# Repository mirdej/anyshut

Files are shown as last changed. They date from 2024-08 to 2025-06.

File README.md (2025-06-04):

# THE   [ a n y m a ]   SHUTTER

Versatile, modular ,3D-printed, remote controlled shutter for video beamers and other light sources.
 
- Can be mounted to the projector in various ways
- Opens to the front or to the side
- Test button on the device
- Wireless remote control through ESP-Now over ~25m
- DMX input to the remote, no need to install cables

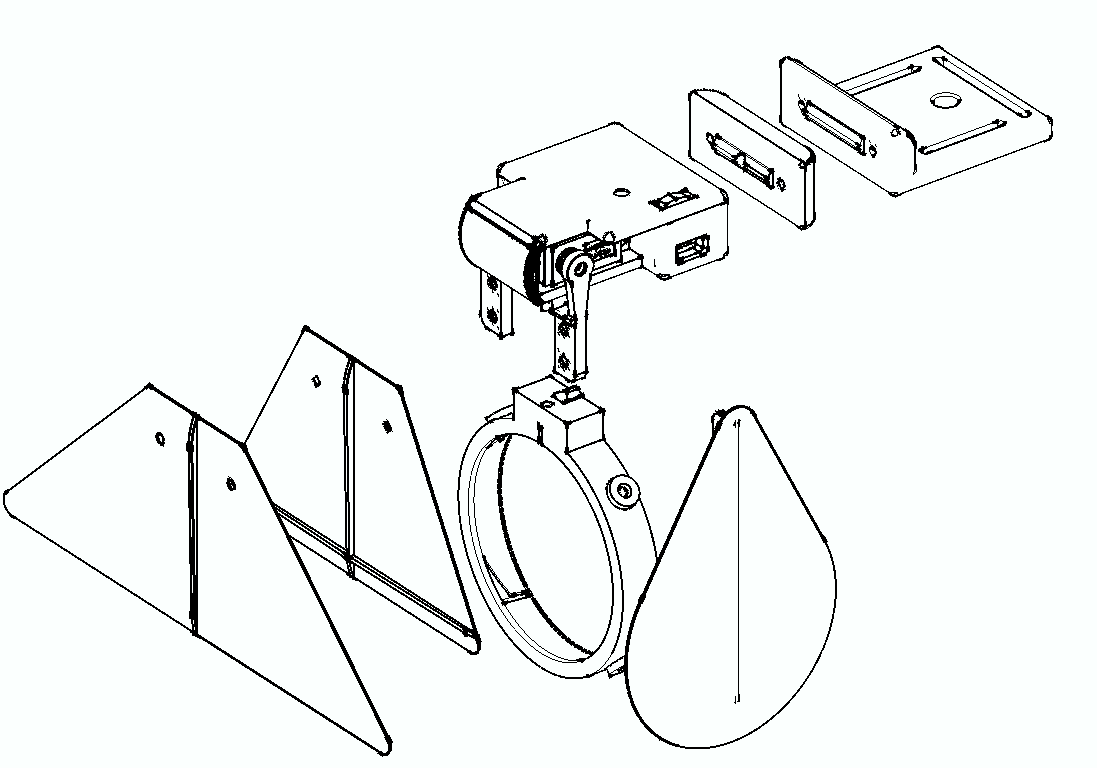
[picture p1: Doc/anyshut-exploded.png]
exploded view


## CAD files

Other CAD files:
Hardware/3D/AnyShut.skp
Hardware/3D/AnyShut~.skp

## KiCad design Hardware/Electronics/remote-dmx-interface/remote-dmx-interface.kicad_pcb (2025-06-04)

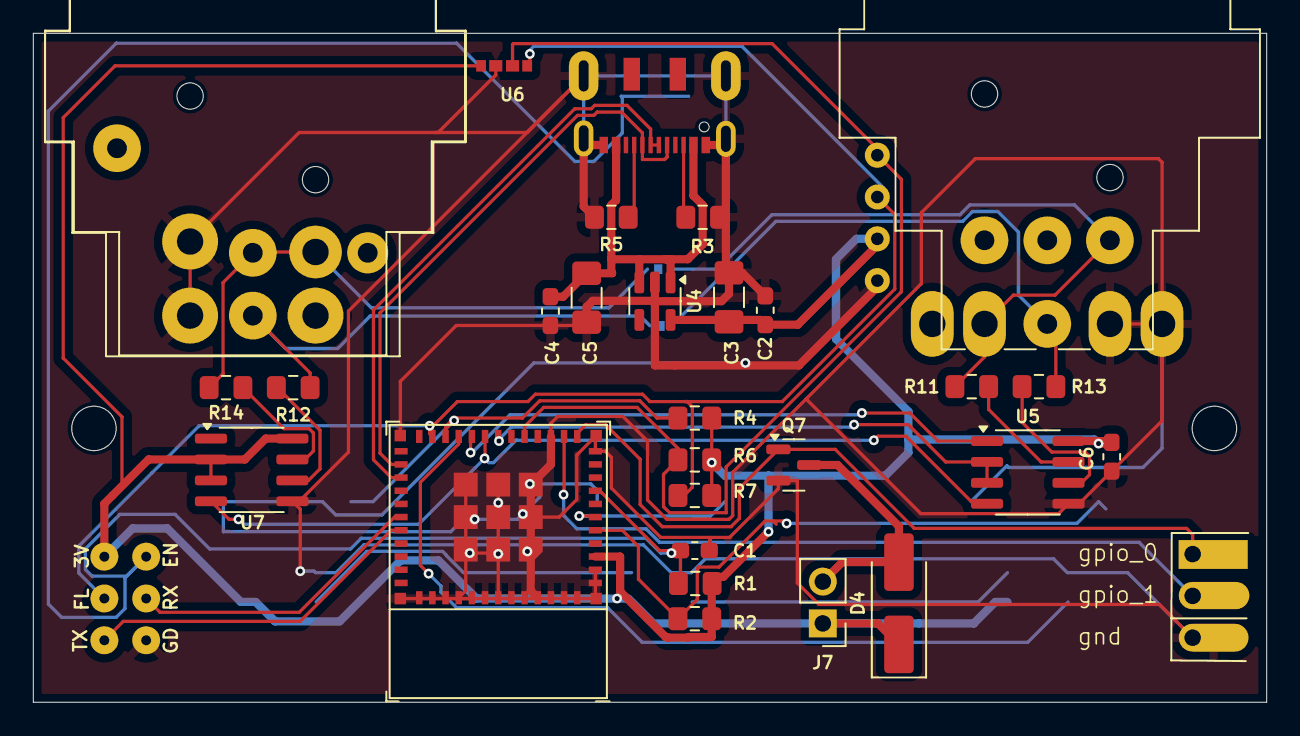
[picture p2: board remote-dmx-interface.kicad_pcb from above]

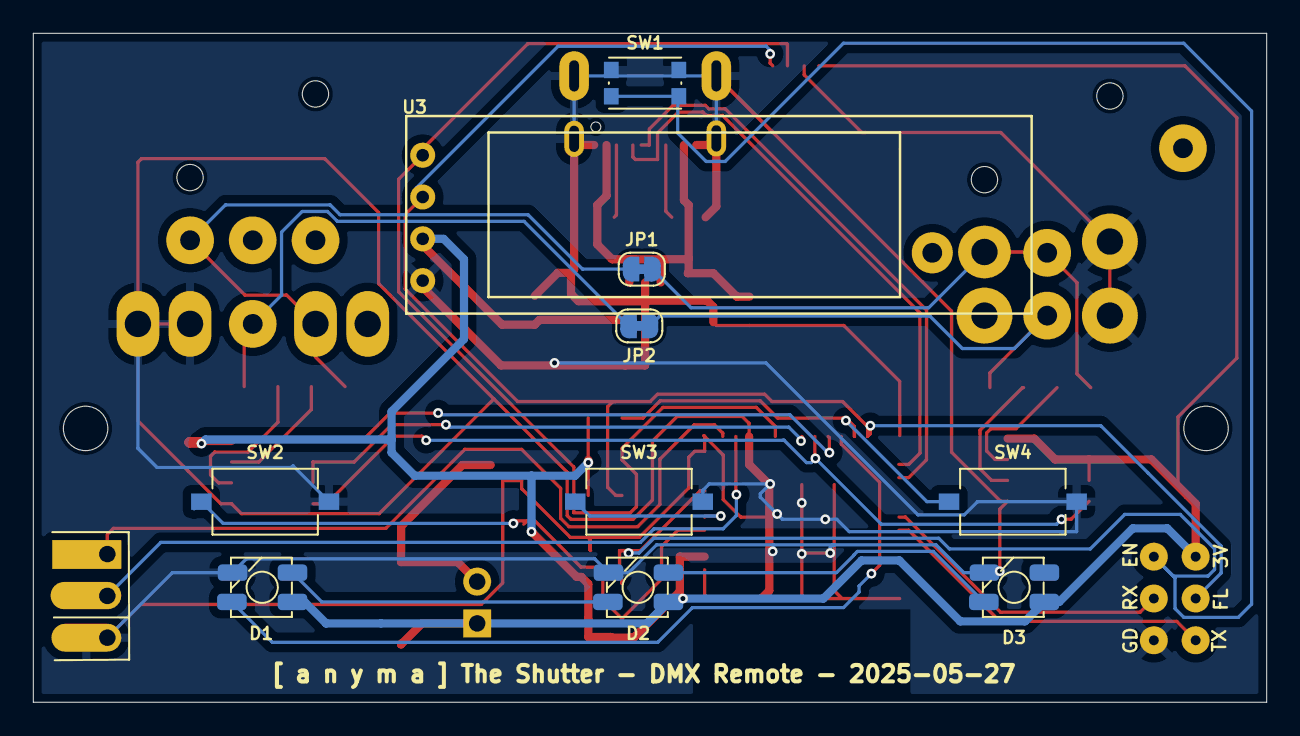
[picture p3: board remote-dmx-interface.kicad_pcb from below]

Board: 2 copper layers, 74.9 x 40.6 mm, 42 parts (11 on the bottom side), 32 nets.

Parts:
C1: 1u; C_0603_1608Metric_Pad1.05x0.95mm_HandSolder
C2, C4, C6: 100n; C_0603_1608Metric_Pad1.05x0.95mm_HandSolder
C3, C5: 10u; C_1206_3216Metric_Pad1.42x1.75mm_HandSolder
D1, D2, D3: SK6812MINI; SK6812-MINI-HS
D4: 1N4148WT; D_SMA_Handsoldering
H2, H5: MountingHole; MountingHole_2.7mm_M2.5_DIN965
J2: Prog; ESP-POGO-PROG-THT
J3: USB_C_Receptacle_USB2.0; JAE_USB-C_SJ122205
J4: DMX-OUT; Jack_XLR_Neutrik_3+5Pin_Female
J5: spare; ComboPinhead_03
J6: DMX-IN; Jack_XLR_Neutrix__3+5Pin_Male
J7: Vibro; PinHeader_1x02_P2.54mm_Vertical
JP1: Cut for MERGER Mode; SolderJumper-2_P1.3mm_Bridged_RoundedPad1.0x1.5mm
JP2: Cut for MERGER mode; SolderJumper-2_P1.3mm_Bridged_RoundedPad1.0x1.5mm
Q7: IRLML0030TRPBF; SOT-23
R1, R2, R3, R4, R5, R6, R7: 5k1; R_0805_2012Metric_Pad1.15x1.40mm_HandSolder
R11, R13: 22; R_0805_2012Metric_Pad1.15x1.40mm_HandSolder
R12, R14: (22); R_0805_2012Metric_Pad1.15x1.40mm_HandSolder
SW1: Reset; SW_Push_1P1T_NO_CK_KMR2
SW2: Btn-1; SW_Tactile_SPST_NO_Straight_CK_PTS636Sx25SMTRLFS
SW3: Btn-2; SW_Tactile_SPST_NO_Straight_CK_PTS636Sx25SMTRLFS
SW4: Btn-3; SW_Tactile_SPST_NO_Straight_CK_PTS636Sx25SMTRLFS
U1: ESP32-C3-MINI-1
U3: i2c-display128x32; Bangood-OLED-128x32
U4: XC6220B331MR; SOT-23-5
U5: SP3485EN; SOIC-8_3.9x4.9mm_P1.27mm
U6: VEML3328; VEML3328SL
U7: (SP3485EN) for MERGER Mode; SOIC-8_3.9x4.9mm_P1.27mm

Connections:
+3V3: C2.1, C3.1, C6.1, D1.4 (VDD), D2.4 (VDD), D3.4 (VDD), D4.1 (K), J2.1, J7.1, R1.1, R2.1, R4.1, R6.1, R7.1, U1.3 (3V3), U3.2 (VCC), U4.5 (VOUT), U5.8 (VCC), U6.1 (VCC), U7.2 (~RE), U7.3 (DE), U7.8 (VCC)
+5V: C4.1, C5.1, J3.A4 (VBUS), J3.A9 (VBUS), U4.1 (VIN), U4.3 (CE)
/DMX_DIR: U1.18 (GPIO4/ADC1_CH4), U5.2 (~RE), U5.3 (DE)
/DMX_RX: U1.20 (GPIO6), U5.1 (RO)
/DMX_TX: U1.19 (GPIO5/ADC2_CH0), U5.4 (DI), U7.4 (DI)
/en: C1.1, J2.2, R1.2, SW1.2, U1.8 (EN/CHIP_PU)
/flash: J2.3, R7.2, U1.23 (GPIO9), U3.3 (SCL), U6.4 (SCL)
/gpio_0: J5.1, Q7.1 (G), U1.12 (GPIO0/ADC1_CH0/XTAL_32K_P)
/gpio_1: J5.2, U1.13 (GPIO1/ADC1_CH1/XTAL_32K_N)
/pix: D1.3 (DIN), U1.21 (GPIO7)
/rx: J2.4, U1.30 (GPIO20/U0RXD)
/sda: R6.2, U1.16 (GPIO10), U3.4 (SDA), U6.3 (SDA)
/strap1: R4.2, SW4.1, U1.22 (GPIO8)
/strap2: R2.2, SW2.1, U1.5 (GPIO2/ADC1_CH2)
/tx: J2.5, U1.31 (GPIO21/U0TXD)
/usb+: J3.A6 (D+), J3.B6 (D+), U1.27 (GPIO19/USB_D+)
/usb-: J3.A7 (D-), J3.B7 (D-), U1.26 (GPIO18/USB_D-)
GND: C1.2, C2.2, C3.2, C4.2, C5.2, C6.2, D1.2 (VSS), D2.2 (VSS), D3.2 (VSS), J2.6, J3.A1 (GND), J3.A12 (GND), J3.S1 (SHIELD), J4.1, J5.3, J6.1, Q7.2 (S), R3.2, R5.2, SW1.1, SW2.2, SW3.2, SW4.2, U1.1 (GND), U1.2 (GND), U1.11 (GND), U1.14 (GND), U1.36 (GND), U1.37 (GND), U1.38 (GND), U1.39 (GND), U1.40 (GND), U1.41 (GND), U1.42 (GND), U1.43 (GND), U1.44 (GND), U1.45 (GND), U1.46 (GND), U1.47 (GND), U1.48 (GND), U1.49 (GND), U1.50 (GND), U1.51 (GND), U1.52 (GND), U1.53 (GND), U3.1 (GND), U4.2 (GND), U5.5 (GND), U6.2 (GND), U7.5 (GND)
unnamed: D1.1 (DOUT), D2.3 (DIN)
unnamed: D2.1 (DOUT), D3.3 (DIN)
unnamed: D4.2 (A), J7.2, Q7.3 (D)
unnamed: J3.A5 (CC1), R3.1
unnamed: J3.B5 (CC2), R5.1
unnamed: J6.2, JP1.1 (A), R11.1
unnamed: J4.2, JP1.2 (B), R14.1
unnamed: J6.3, JP2.1 (A), R13.1
unnamed: J4.3, JP2.2 (B), R12.1
unnamed: SW3.1, U1.6 (GPIO3/ADC1_CH3)
unnamed: R13.2, U5.6 (A)
unnamed: R11.2, U5.7 (B)
unnamed: R12.2, U7.6 (A)
unnamed: R14.2, U7.7 (B)

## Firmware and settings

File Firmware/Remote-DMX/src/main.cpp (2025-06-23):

#include <Arduino.h>
#include <FastLED.h>
#include "Display.h"
#include <Agora.h>
#include <esp_dmx.h>

#define PING_INTERVAL 1000

dmx_port_t dmxPort = 1;
#define RX_SIZE 512
byte data[RX_SIZE];

bool dmxIsConnected = false;

unsigned long lastInteraction = 0;
unsigned long lastUpdate = millis();

const int NUM_BTNS = 3;
const int PIN_BTN[NUM_BTNS] = {2, 3, 8};

const int NUM_PIXELS = 3;
CRGB pixel[NUM_PIXELS];
CRGB pixel_buf[NUM_PIXELS];
Preferences preferences;

#define PIN_DMX_RX 6
#define PIN_PIX 7

#define MESS_GET_SHUTTER 1
#define MESS_SET_SHUTTER 2

typedef struct esp_now_message
{
  //  uint8_t mac[6];
  uint8_t message;
  uint8_t param;
} esp_now_message;

int last_btn[NUM_BTNS];
int dmx_address = 1; // DMX address starts at 1
int shutter_closed = 1;

//--------------------------------------------------------------------------------

void updateDisplay()
{
  char buf[8];
  sprintf(buf, "%03d", dmx_address);
  if (dmxIsConnected)
  {
    display("    DMX OK    ", buf);
  }
  else
  {

    display("---No DMX---", buf);
  }
}

//--------------------------------------------------------------------------------
// Callback when data is received
void OnDataRecv(const uint8_t *mac, const uint8_t *incomingData, int len)
{
  Serial.printf("Message from Controller: %s\n", incomingData);
  if (!strcmp((const char *)incomingData, "OPEN"))
  {
    shutter_closed = 0;
  }
  else if (!strcmp((const char *)incomingData, "CLOSED"))
  {
    shutter_closed = 1;
  }
}

//----------------------------------------------------------------------------------------
//																				                                        LED Task

void led_task(void *)
{

  FastLED.addLeds<SK6812, PIN_PIX, GRB>(pixel, NUM_PIXELS);
  FastLED.setBrightness(250);
  for (int hue = 0; hue < 360; hue++)
  {
    fill_rainbow(pixel, NUM_PIXELS, hue, 7);
    delay(5);
    FastLED.show();
  }

  log_v("Running Led task");

  while (1)
  {
    fill_solid(pixel, NUM_PIXELS, Agora.connected() ? CRGB(6, 6, 6) : CRGB::DarkBlue);
    pixel[1] = shutter_closed ? CRGB::Red : CRGB::Green; // Button 2 shows shutter status
    for (int i = 0; i < NUM_BTNS; i++)
    {
      if (!digitalRead(PIN_BTN[i]))
      {
        pixel[i] = CRGB::LightCyan;
      }
    }
    FastLED.show();
    vTaskDelay(pdMS_TO_TICKS(40)); // ~25 fps display
  }

  vTaskDelete(NULL); // we never get here
}

//----------------------------------------------------------------------------------------
void toggleShutter()
{
  char buf[20];
  memset(buf, 0, sizeof(buf));
  sprintf(buf, "%s", shutter_closed ? "OPEN" : "CLOSE");
  Agora.tell(buf, sizeof(buf));
}
//----------------------------------------------------------------------------------------
//																				                                      Button Task

void button_task(void *)
{
  int last_button_state[NUM_BTNS];
  unsigned long lastButtonPress[NUM_BTNS] = {0, 0, 0};
  int button_state;
  int step = 1;

  for (int i = 0; i < NUM_BTNS; i++)
  {
    pinMode(PIN_BTN[i], INPUT_PULLUP);
    last_button_state[i] = digitalRead(PIN_BTN[i]);
  }

  Serial.printf("Running Button task");
  while (1)
  {
    int lastDmxAddress = dmx_address;
    for (int i = 0; i < NUM_BTNS; i++)
    {
      button_state = digitalRead(PIN_BTN[i]);
      if (i == 1)
      {
        step = button_state ? 1 : 10; // Button 2 changes step size
      }

      if (button_state != last_button_state[i])
      {
        last_button_state[i] = button_state;
        if (!button_state)
        {
          Serial.printf("Button %d pressed\n", i);
          lastButtonPress[i] = millis();
          if (i == 0)
          {
            dmx_address -= step;
          }
          else if (i == 1) // Button 2
          {
            toggleShutter();
          }
          else if (i == 2)
          {
            dmx_address += step;
          }
          else
          {
            lastButtonPress[i] = 0;
          }
        }
        else
        {
          lastButtonPress[i] = 0;
        }
      }

      if (lastButtonPress[i] > 0 && (millis() - lastButtonPress[i]) > 126)
      {
        lastButtonPress[i] = millis(); // reset button press
        if (i == 0)                    // Button 1
        {
          dmx_address -= step;
        }
        else if (i == 2) // Button 3
        {
          dmx_address += step;
        }
      }
    }
    if (dmx_address < 1)
    {
      dmx_address += 512; // wrap around to 512
    }
    if (dmx_address > 512)
    {
      dmx_address -= 512; // wrap around to 1
    }
    if (dmx_address != lastDmxAddress)
    {
      lastInteraction = millis();
      updateDisplay();
    }
    vTaskDelay(pdMS_TO_TICKS(25));
  }
}

//--------------------------------------------------------------------------------

void setup()
{

  xTaskCreate(led_task, "LED Task", 8192, NULL, 1, NULL);

  Serial.begin(115200);
  vTaskDelay(pdMS_TO_TICKS(1000));

  log_v("________________________");
  log_v("Setup");

  xTaskCreate(button_task, "Button", 8192, NULL, 2, NULL);

  preferences.begin("DMX-To-Anyspot");
  dmx_address = preferences.getInt("dmx_address", 1);
  Serial.printf("DMX Address: %d\n", dmx_address);

  dmx_config_t config = DMX_CONFIG_DEFAULT;
  dmx_personality_t personalities[] = {
      {1, "Default Personality"}};
  int personality_count = 1;
  dmx_driver_install(dmxPort, &config, personalities, personality_count);
  dmx_set_pin(dmxPort, -1, PIN_DMX_RX, -1);

  init_display();
  Agora.begin("Anyshut-DMX");
  Agora.establish("anyshut", OnDataRecv);
  Agora.setPingInterval(PING_INTERVAL);

  log_v("Setup Done");
  log_v("________________________");
}
//--------------------------------------------------------------------------------

void loop()
{

  delay(10);
  static char lastVal;

  dmx_packet_t packet;

  if (dmx_receive(dmxPort, &packet, DMX_TIMEOUT_TICK))
  {

    /* We should check to make sure that there weren't any DMX errors. */
    if (!packet.err)
    {
      /* If this is the first DMX data we've received, lets log it! */
      if (!dmxIsConnected)
      {
        dmxIsConnected = true;
        updateDisplay();
      }

      dmx_read(dmxPort, data, RX_SIZE);
      uint8_t val = data[dmx_address] > 127 ? 1 : 0; // DMX values are 0-255, we use 0 for closed, 1 for open
      if (val != lastVal)
      {
        shutter_closed = lastVal;
        toggleShutter();
        lastVal = val;
      }
    }

    else
    {
      Serial.println("A DMX error occurred.");
    }
  }
  else if (dmxIsConnected)
  {

    Serial.println("DMX was disconnected.");
    updateDisplay();
    dmxIsConnected = false;
  }

  if (lastInteraction > 0 && (millis() - lastInteraction) > 3000)
  {
    lastInteraction = 0;
    preferences.putInt("dmx_address", dmx_address);
    Serial.printf("DMX Address saved: %d\n", dmx_address);
  }
}

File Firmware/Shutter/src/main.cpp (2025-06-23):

/*========================================================================================

[ a n y m a ]
AnyShut - (DMX) Beamer Shutter


© 2024 Michael Egger AT anyma.ch
Licensed under GNU GPL 3.0

==========================================================================================*/
//                                                                                      LIB

#include <Arduino.h>
#include "FastLED.h"
#include "ServoEasing.hpp"
#include "Agora.h"
#include "Preferences.h"

const int PIN_SERVO = 5;
const int PIN_PIXEL = 17;
const int PIN_BUTTON = 6;

int shutter_closed = 1;
int position_closed = 170;
int position_open = 30;
int shutter_speed = 360;

//----------------------------------------------------------------------------------------
//																				                                     User Globals
#define NUM_PIXEL 1
CRGB pixel[NUM_PIXEL];
ServoEasing myservo;
int last_btn;

#define SERVO_DEGREES_PER_SECOND 360

#define PING_INTERVAL 1000


void send_shutter_state();
bool connected;

unsigned long lastStateSent = 0;

//--------------------------------------------------------------------------------
void set_shutter()
{
  unsigned long start = millis();

  pixel[0] = CRGB::DarkViolet;
  FastLED.show();
  delay(20);

  if (shutter_closed == 1)
  {
    myservo.easeTo(position_open, SERVO_DEGREES_PER_SECOND); // set the servo position according to the scaled value
  }
  else
  {
    myservo.easeTo(position_closed, SERVO_DEGREES_PER_SECOND);
  }
  send_shutter_state();
  Serial.printf("Time to move: %dms", millis() - start);
}

//----------------------------------------------------------------------------------------
void myCallback(const uint8_t *macAddr, const uint8_t *incomingData, int len)
{
  Serial.printf("Message from Controller: %s\n", incomingData);
  if (!strcmp((const char *)incomingData, "OPEN"))
  {
    shutter_closed = 0;
    set_shutter();
  }
  else if (!strcmp((const char *)incomingData, "CLOSE"))
  {
    shutter_closed = 1;
    set_shutter();
  }
}

//----------------------------------------------------------------------------------------

void send_shutter_state()
{
  char buf[20];
  memset(buf, 0, sizeof(buf));
  sprintf(buf, "%s", shutter_closed ? "CLOSED" : "OPEN");
  Agora.tell(buf, sizeof(buf));
}

//========================================================================================
//----------------------------------------------------------------------------------------
//																				                                           Setup
void setup()
{

  Serial.begin(115200);
  vTaskDelay(pdMS_TO_TICKS(1000));
  log_v("%s", PROJECT_PATH);
  log_v("Version %s", FIRMWARE_VERSION);

  log_v("________________________");
  log_v("Setup");

  FastLED.addLeds<SK6812, PIN_PIXEL, GRB>(pixel, NUM_PIXEL);
  FastLED.setBrightness(100);
  for (int hue = 0; hue < 360; hue++)
  {
    fill_rainbow(pixel, NUM_PIXEL, hue, 7);
    delay(5);
    FastLED.show();
  }

  pinMode(PIN_BUTTON, INPUT_PULLUP);
  last_btn = digitalRead(PIN_BUTTON);

  myservo.setEasingType(EASE_CUBIC_IN_OUT); // EASE_LINEAR is default
  myservo.attach(PIN_SERVO, position_closed);

  Agora.begin("Shutter", true);
  Agora.join("anyshut", myCallback);
  Agora.setPingInterval(PING_INTERVAL);
  log_v("Setup Done");
  log_v("________________________");
}

//========================================================================================
//----------------------------------------------------------------------------------------
//																				Loop

void loop()
{
  int btn = digitalRead(PIN_BUTTON);
  /* log_v("Btn %d", btn);
  delay(1000);
   */

  if (btn != last_btn)
  {

    last_btn = btn;
    if (!btn)
    {
      log_v("Btn pressed");

      shutter_closed = shutter_closed ? 0 : 1;
      set_shutter();
    }
  }

  CRGB led_color;
  if (!shutter_closed)
  {
    led_color = Agora.connected() ? CRGB::DarkGray : CRGB::Orange;
  }
  else
  {
    led_color = Agora.connected() ? CRGB::Blue : CRGB::Red;
  }

  if (pixel[0] != led_color)
  {
    pixel[0] = led_color;
    FastLED.show();
  }

  if (millis() - lastStateSent > 5000)
  {
    send_shutter_state();
    lastStateSent = millis();
  }
}

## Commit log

2024-07-19 initaial commit
    [AnyShut.skp]
2024-08-03 cleanup 3d, readme
    [remote-dmx-interface.kicad_pcb, remote-dmx-interface.kicad_sch]
2025-06-04 remote dmx - new hardware, old firmware
    [remote-dmx-interface.kicad_pcb, remote-dmx-interface.kicad_sch]
2025-06-23 switch to Agora
